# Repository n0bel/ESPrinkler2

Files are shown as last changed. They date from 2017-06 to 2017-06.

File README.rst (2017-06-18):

ESPrinkler2
===========
Arduino/ESP8266 based sprinkler Controller.
-------------------------------------------

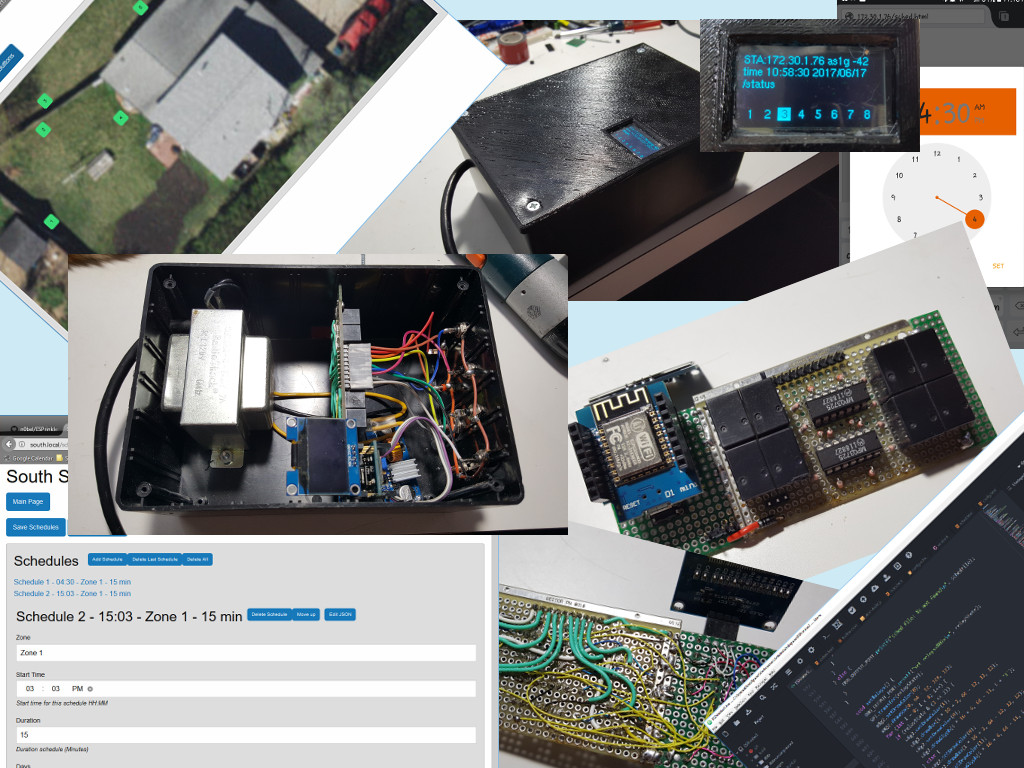
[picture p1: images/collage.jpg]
ESPrinkler2 Collage


This is a totally rewritten second version of
https://github.com/n0bel/ESPrinkler Consider that code now totally
obsolete.

This project uses Arduino/ESP8266 to create a web based lawn/garden
sprinkler controller.

Features
--------
-  Web server based (ESP8266WebServer)
-  Responsive UI (desktop/mobile/tablet) written around Jquery,
   Foundation5, and jsoneditor
-  8 Zones (relays)
-  Up to 30 Schedules
-  NTP Time (or set from browser)
-  RTC Option pcf8563 or ds1307
-  OLED Display Option
-  ArduinoOTA update (code and spiffs)
-  HTTP Server Update (code and spiffs)

Requirements
------------
Hardware
~~~~~~~~
-  ESP-12x (nodemcu, hazza, D1 Mini) (probably others)
-  74HC595
-  ST1306 OLED
-  PCF8563 or ds1307 (optional)
-  Relays

Software
~~~~~~~~
-  Arduino-1.8.3
-  ESP8266/Arduino :Additional Boards Manager URL:
   http://arduino.esp8266.com/stable/package\_esp8266com\_index.json
-  Time 1.5.0 https://github.com/PaulStoffregen/Time
-  SimpleTimer https://github.com/jfturcot/SimpleTimer
   (http://playground.arduino.cc/Code/SimpleTimer)
-  NtpClientLib 2.0.5 https://github.com/gmag11/NtpClient
-  ArduinoJson 5.6.7 https://github.com/bblanchon/ArduinoJson
   (https://bblanchon.github.io/ArduinoJson/)
-  U8G2Lib 2.13.5 https://github.com/olikraus/u8g2
-  orbitalair-arduino-rtc-pcf8563
   https://bitbucket.org/orbitalair/arduino\_rtc\_pcf8563/downloads/
   (https://playground.arduino.cc/Main/RTC-PCF8563)

General Instructions
--------------------

Hardware
~~~~~~~~
This project requires DIY assembly and soldering skills.  At this time there
is no pre-made board.  I've made two of these systems so far, and both of them
are done with proto boards and point to point wiring and assembled in a
water resistant project box.

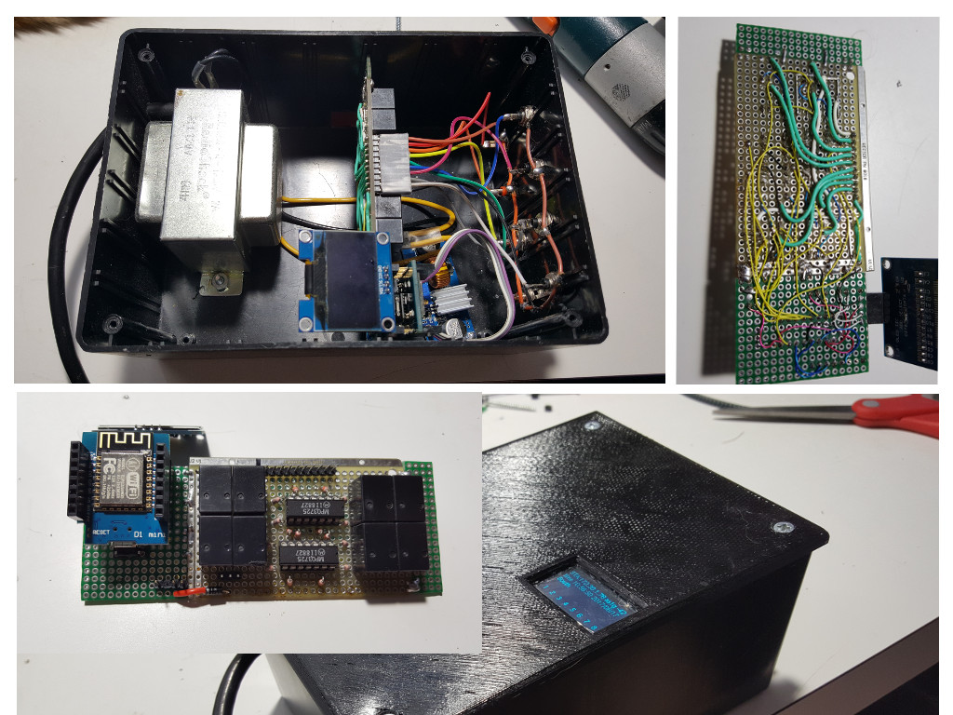
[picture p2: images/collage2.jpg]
ESPrinkler2 An example build


General Hardware Description
^^^^^^^^^^^^^^^^^^^^^^^^^^^^

An ESP8266 with 4MB (32Mb) of flash is required.  The software makes extensive
use of the flash storage for both OTA updates and spiffs.  Generally this is
an ESP-12x, but other models may be used.  In my case I used a WeMos D1 Mini
as the ESP8266 board.  I had some in the junk box and it has the 3.3v
regulator, and the usb to serial interface built on board.  It also includes
a nodemcu type reset and programming circuit.

The 8 relays are controlled through a 74HC595 8 bit shift register.   This is
simply wired to the SPI interface of the ESP8266 (CS (GPIO15), CLK (GPIO14),
MOSI (GPIO13) connected to Latch, Clock and Data In of the 74HC595).

The shift register outputs are then connected via resistors (10k or so) to the
8 NPN transistors acting as relay drivers.  In my particular case I had some
quad transistors in a 14 pin dip package in my junk box.

These transistors then drive 8 mini 5v relays.  The relay contacts connect
24vac to the corresponding output, and therefore energize a sprinkler solenoid.

A 24vac center tapped transformer powers it all.   One leg of the transformer
output is ground for the circuit, the other side is routed to the relays to
control the solenoids.   The center tap is rectified through a single diode
to feed the input of a buck type dc-dc switch mode converter.  The output
of the convert is set to 5v and is routed to the relays and to the D1 Mini.

The ST1306 OLED is an I2C device and therefore connected to SCL (GPIO5)
and SDA (GPIO4) of the ESP8266.

For the optional real time clock (pcf8563 or ds1307), I rigged that up on a
proto board stacked on the D1 Mini using stacking pins.

The following schematic can be used as a guide.  A Fritzing file is also
included.  It is also just a guide.  Again DIY assembly and soldering skills
are required to complete this project.

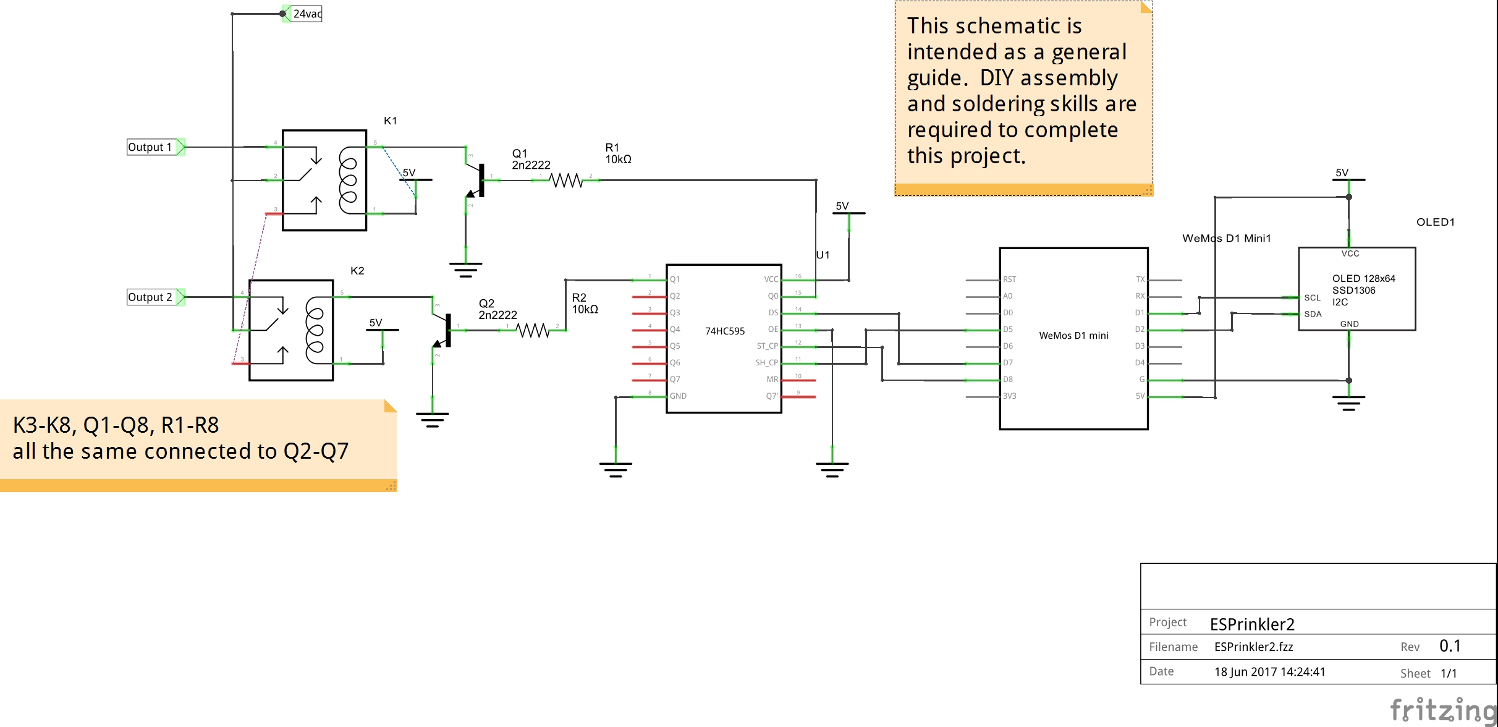
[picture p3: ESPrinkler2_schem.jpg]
ESPrinkler2 Guide Schematic


Software
~~~~~~~~
Don't forget to restart the Arduino IDE after installing the libraries
and boards (See the list previously under Software).

Set your esp settings.. the board, programing method, flash size 4M3M.

This uses the SPIFFS file system. So we need to load that in your
esp-12x first. For quicker loading of web pages, almost all the files on
the spiffs flash are gzip compressed and they have the suffix ".gz".
The uncompressed data version of all the files is the "Master" in the
"data-uncompressed" folder.   The compress-data.cmd file (windows) will
compress the data in preparation for uploading.  If you've not made any
changes to the contents of data-uncompressed, you don't need to do this step.

Upload the contents of the data folder with MkSPIFFS Tool
("ESP8266 Sketch Data Upload" in Tools menu in Arduino IDE)

Then compile and upload the .ino.

Setup
~~~~~
When initially powered on, the internet access point will not be setup.
The ESPrinkler will therefore switch to AP mode. It will be come an
access point in itself.

So connect to ESPrinkler2_XXXXXX with a wifi enabled device (no
password).

Browse to 192.168.4.1

The initial page will let you toggle the relays on/off to test.

But the first thing you'll want to do is click "Set Time from Browser".  Both
the time and the correct time zone are now set up.

Now go to the Configuration page

Set a host name.  This will help allow you to access the device from your
browser (if you can use mDNS).

Set your access point name and password. You have 2 choices here.

-  If you want to connect the device to your network, fill in your access
   point SSID and password.
-  If you want to leave it as a stand alone access point all by itself,
   fill in the second set of SSID and Password, to secure the access point.

Click Save Configuration, then click Restart.

What is it's IP? If your computer supports mDNS (Anything but windows,
but even on windows it'll be there if you have loaded iTunes), you can
access it with the following url: http://<host>.local/, where
<host> is the host you specified in your configuration.  If you don't
have mDNS available, you must find the IP address of the ESPrinkler2
through one of the following methods (or make up your own method)

-  Look at the OLED display (if you're using one)
-  Log into your router and look at the dhcp leases (sometimes called
   dhcp client list) find the entry that shows ESP_xxxxxx
-  Connect a serial ttl dongle to the ESPrinkler2, set the baud rate to
   74880. During startup, you'll see the IP address shown.
-  Get mDNS on your computer: here's some info for windows:
   http://stackoverflow.com/questions/23624525/standard-mdns-service-on-windows
-  ping from a computer that does handle mDNS -- ping <hostname>.local

General usage
~~~~~~~~~~~~~

The Main web page of ESPrinkler2 allows you to test each of the 8 relays. Of
course it also allows navigation to the other pages.  The web pages use a
combination of jQuery, and Foundation5 to create a simple UX that is also
responsive to Desktop, Mobile and Tablet formats.  In addition JsonEditor is
used to simplify entering/editing the settings and schedules.  The frameworks
are all loaded onto the spiffs of the device, so it will work even when no
internet is connected.

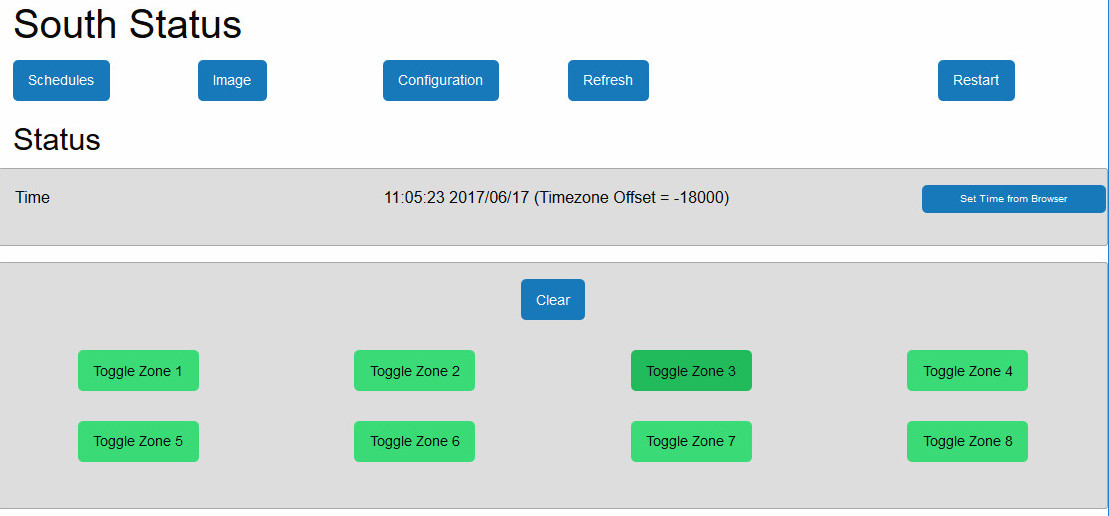
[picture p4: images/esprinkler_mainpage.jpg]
ESPrinkler2 Main Page


The OLED Screen
^^^^^^^^^^^^^^^
The OLED screen gives the current status of the device, as well as its IP
address.

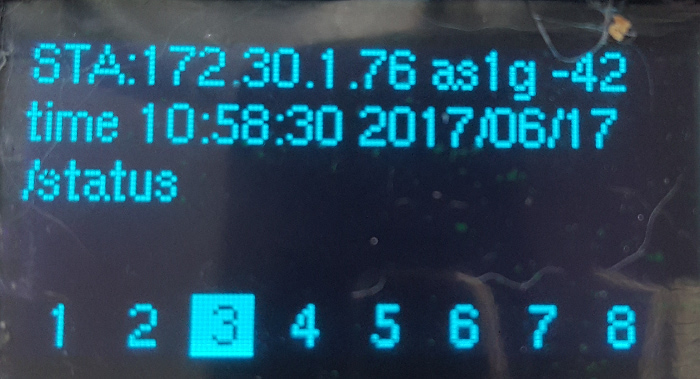
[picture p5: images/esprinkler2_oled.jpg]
ESPrinkler2 OLED Screen


The top line will show the WiFi Status.
-  STA: IP address means connected in Station mode to an access point.
-  AP: IP address means it is acting as an access point.  The second line
   will show the access point name
-  DIS: means it is disconnected.

The bottom line shows that status of each zone (relay).

Schedules
^^^^^^^^^

The schedules page allows adding, specifying and arranging schedules of when
to turn on and off each zone (relay).  Start time, duration, days of week, are
each set for each schedule.  Up to 30 schedules may be setup.

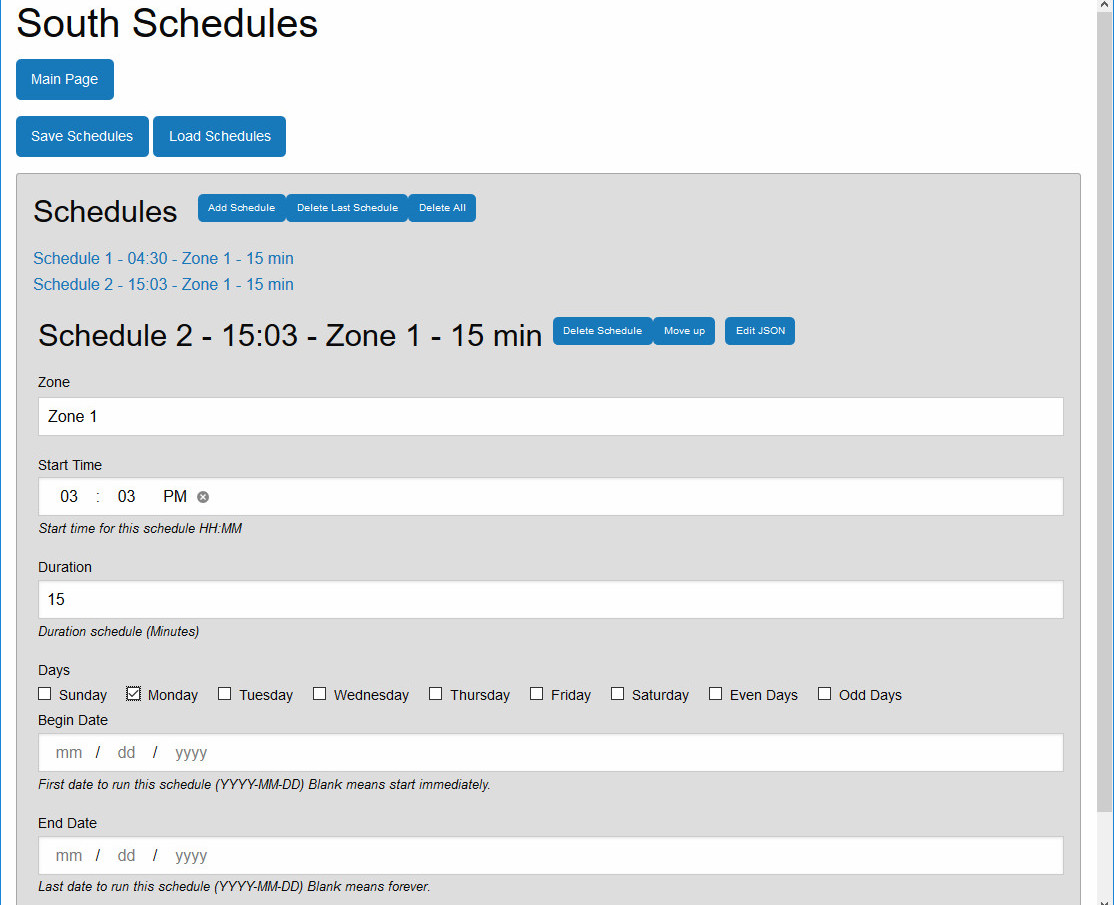
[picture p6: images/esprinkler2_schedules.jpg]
ESPrinkler2 Schedules Page


The Image Page
^^^^^^^^^^^^^^

The image page gives you a graphical representation of each sprinkler zone.
This is handy when testing your sprinklers and setting them up.

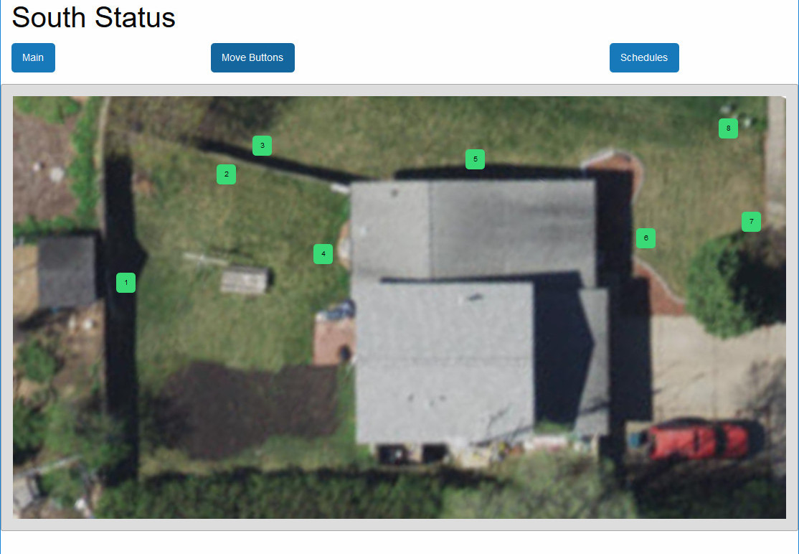
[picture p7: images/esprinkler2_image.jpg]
ESPrinkler2 Image Page


There is a default image supplied, and by default 8 buttons, representing each
zone appear along the top of the image.  The image could be a sketch or a
satellite image of the are the sprinklers are installed.

The "Move Buttons" button can be activated, and the buttons may be moved
around the image (mouse or touch) to indicate which zone is where on the image.
"Save Buttons" then saves the button locations.

The name of the image file is simply "image.jpg" and it can be placed into the
data-uncompressed and/or data folder before loading the spiffs into the device.
It can also be uploaded using the built in spiffs editor (discussed later in
this document.)

Configuration Page
^^^^^^^^^^^^^^^^^^

The configuration page allows you to set the ESPrinkler2 as needed.

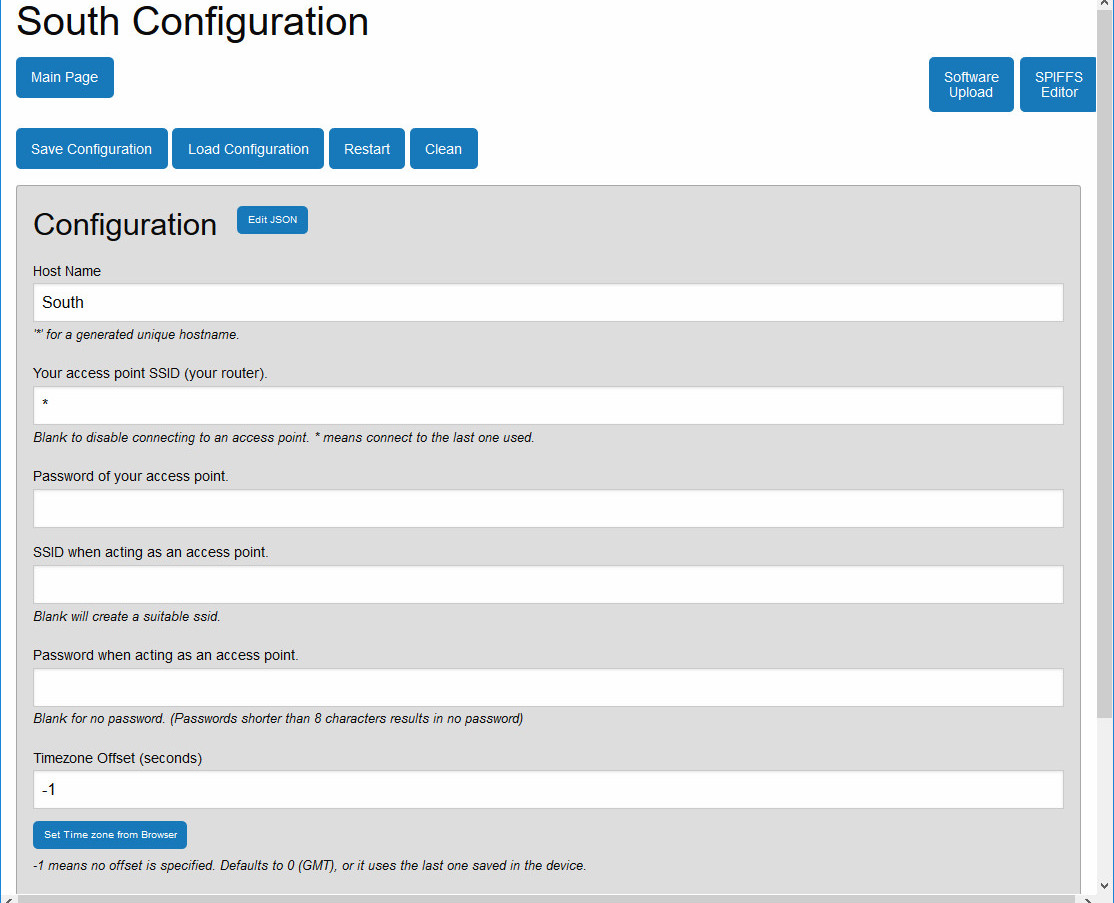
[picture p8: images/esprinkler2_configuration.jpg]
ESPrinkler2 Configuration


The save and load configuration buttons are self explanatory.  Restart is a
reset of the ESP8266.  The "Clean" button clears all configuration (and
schedules and button settings).

+----------------+-------------------------------------------------------+
| Config Item    | Description                                           |
+================+=======================================================+
| Host Name      | The name you give to the device. No spaces allowed    |
|                | The default access point name, and the mDNS name will |
|                | use this name.  If not specified ESPrinkler2_XXXXXX   |
|                | (XXXXXX) is the chipid of the device.                 |
+----------------+-------------------------------------------------------+
| Your Access    | If you want to connect the device to your WiFi network|
| Point SSID     | enter its SSID here.                                  |
+----------------+-------------------------------------------------------+
| Password of    | The password of your access point.                    |
| your Access    |                                                       |
| Point          |                                                       |
+----------------+-------------------------------------------------------+
| SSID when      | If you want the device to act as a stand alone access |
| acting as an   | point (i.e. no internet, only direct connect)         |
| access point   | specify that SSID here.  If blank, it will default as |
|                | the Host Name (or host name default)                  |
+----------------+-------------------------------------------------------+
| Password when  | The password for securing the access point.           |
| acting as an   |                                                       |
| access point   |                                                       |
+----------------+-------------------------------------------------------+
| Timezone       | The timezone offset in seconds.  How many seconds     |
| Offset in      | ahead (positive) or behind (negative) of UTC          |
| seconds        | There is a button to allow this to be set from the    |
|                | browser. If you use -1, the last offset specified by  |
|                | Set Time from browser on the main page will be used.  |
+----------------+-------------------------------------------------------+
| NTP Time Server| What time server to use for getting NTP time.  Note   |
|                | this only works when the device is connected to an    |
|                | access point that has internet access.                |
+----------------+-------------------------------------------------------+

Software Update
^^^^^^^^^^^^^^^

On the Configuration Page, there is a "Software Upload" button.  This allows
new firmware or a new spiffs binary to be loaded directly from your browser.
Simply choose the binary image to upload, and then click "Upload!".
This process can take some time.  You can check progress on the OLED screen.

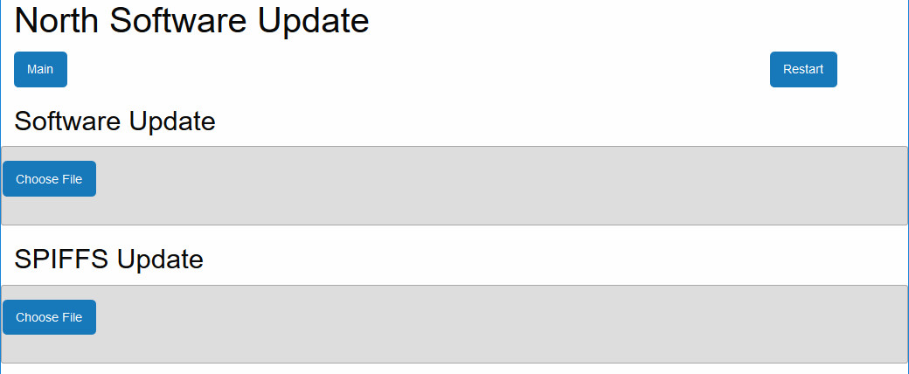
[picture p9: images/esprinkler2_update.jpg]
ESPrinkler2 Update


SPIFFS edit
^^^^^^^^^^^^^^^

On the Configuration Page, there is a "SPIFFS Editor" button.  This allows
you to upload, delete and change the files that the web server uses.

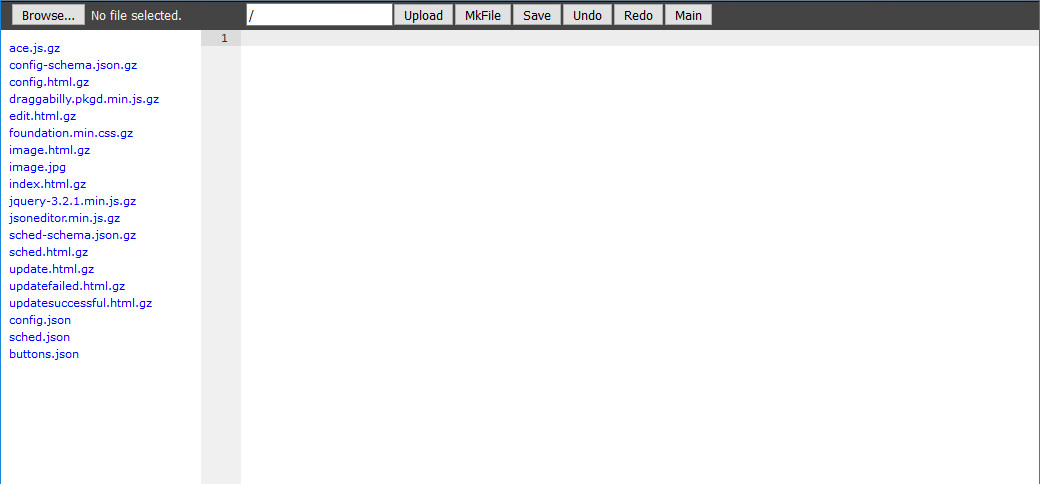
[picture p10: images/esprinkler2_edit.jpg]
ESPrinkler2 SPIFFS editor


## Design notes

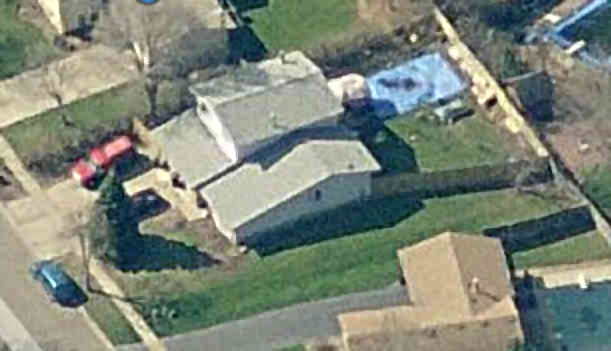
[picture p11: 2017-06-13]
images/house1.jpg

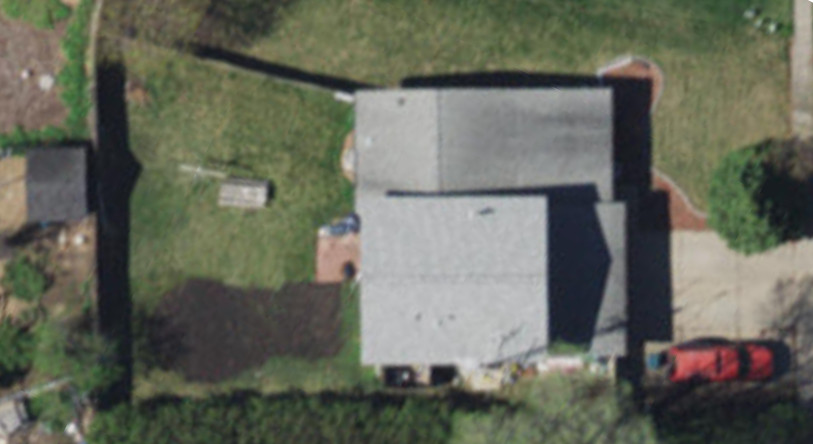
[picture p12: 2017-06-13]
images/house3.jpg

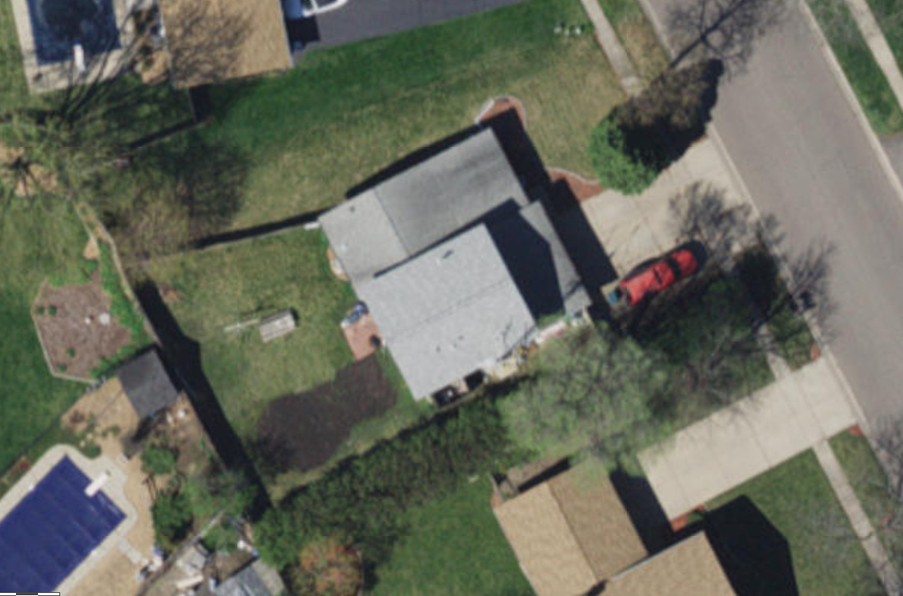
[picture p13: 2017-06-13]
images/house2.jpg

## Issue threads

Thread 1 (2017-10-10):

Cannot create shcedulle more than 8 sched

TeguhTeknisi, 2017-10-10:
I got error when i create more than 8 schedule.
Here some error:
handleFileUpload Name: /sched.json
handleFileUpload Size: 1040
json parse of schedFile failed.

Please help me to solve the problem.

Thanks before.

Meins321, 2020-05-16:
to be honest i don't have this problem, i did build it too witth the wemos d1 mini pro with external antenna and spi flash which is currently not supported...

i can imagine that if you set the flash vs spiff size wrong in arduino ide before you compile and transfer the programm itself the "schedule" file fails due file size..

1.Please test if you run the default setup with nothing changed if you can't create more than 8 tasks

2.Check that you set it to 3M/512k in arduin ide

3. how big is your picture for the Zone Map? <-     :-)

TeguhTeknisi, 2020-05-16:
Hi,
Thanks alot for the reply,I don't play with arduino for around 2 year.but just around 2-3 weeks ago i play with ESPEasy just for setup Temp/Hum Sensor DHT11 and Display 1605 to monitor Temp/Hum in my room and outside my room.
I have delete some of my project files, because i have upgrade my ubuntu, and loose some arduino ide stuff.
And then because i don't know what to do anymore with the ESPrinkler, i move out to OpenSprinkler OSBee - Topic: Need Help to make OSBee Web Offline | OpenSprinkler
|
|
|
|   |    |

   |

  |
|
|   |
Topic: Need Help to make OSBee Web Offline | OpenSprinkler

  |   |

  |

  |

Thats me when i ask some help in the forum, and share my modified osbee sourcecode in there.
i got more fun playing with it, but because some problem (whiteflies,bug,spidermite,etc) with my greenhouse, i have to quit playing with arduino and my greenhouse.
so i'am sory, i cannot answer your question.But for number 3, i use the default picture for zone map, using your.Because my focus still trying to get more schedule, i don't have time to change the picture.
Thanks a lot for your reply and the source code, i have fun and learning from esprinkler2.

Best Regrads,Teguh Teknisi

Sent from Yahoo Mail on Android

  On Sun, May 17, 2020 at 3:57, Meins321<notifications@github.com> wrote:

to be honest i don't have this problem, i did build it too witth the wemos d1 mini pro with external antenna and spi flash which is currently not supported...

i can imagine that if you set the flash vs spiff size wrong in arduino ide before you compile and transfer the programm itself the "schedule" file fails due file size..

1.Please test if you run the default setup with nothing changed if you can't create more than 8 tasks

2.Check that you set it to 3M/512k in arduin ide

   - how big is your picture for the Zone Map? <- :-)

—
You are receiving this because you authored the thread.
Reply to this email directly, view it on GitHub, or unsubscribe.

attiliovaccaro, 2020-10-27:
I had the same problem with even less schedules. The issue is not with the schedules, bud with the length of the generated sched.json which shall be less than 1000 characters.
I tried to increase it to 1500 by changing a couple of lines of code in the loadSched() function and it works. I also tried with larger values, but the system does not work (it continuously reboots after connecting to the WIFI).
I guess that a way to solve this would be to modify the names of attributes/nodes used in sched.json using shorter ones, this would imply some further changes in the code and schema.

Meins321, 2022-02-16:
@attiliovaccaro Can you share more insight? i have created more than 8 shedules back then when i answered and it worked maybe i did test it wrong?

lethedream007, 2022-05-22:
@attiliovaccaro
Not quite sure what core version you are using. I'm using 2.7.4 (NodeMCU ESP8266) and I cannot change the size of the json array without introducing issues (mainly to the WIFI). However, I did find that, if I enable the debug port and set the debug level to "WIFI" or "CORE", everything works. I can even increase the json array size to [5000] with DynamicJsonBuffer, which should allow plenty of schedules.

@Meins321 I think it is also about what boxes you check when you set the schedule. It's very possible that 8 schedules don't run over 1000 characters.

I'm still puzzled why I must enable debug port for "WIFI" or "CORE" to make the code work. I have been reading random post online and it could be related to some variables not initialized correctly, race condition, etc. I'm lost...

YengaJaf-Aizatron, 2024-06-26:
This is an old issue, but what I did was to increase the stack size of the main loop, and increase the jsondoc size. At first I made the JsonDoc size 5000, but then I ran into a stack overflow issue. What fixed it was this line which I placed right at the beginning of the main.c file:
`/*
Increase stack of main loop, Default 8k
This was done to allow schedules more than 8 to work
*/
SET_LOOP_TASK_STACK_SIZE(16*1024);`

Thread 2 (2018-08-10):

Support for this premade board?

oleost, 2018-08-10:
Hi.

Any chance this could work on this premade board?

"Esp8266 4ch 12v wifi relay"
https://www.aliexpress.com/item/ESP8266-4CH-12V-WiFi-Relay-Module-Smart-Home-Mobile-APP-Remote-Control-Switch/32879651251.html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,searchweb201602_1_10152_10065_10151_10344_10068_10342_10343_10340_10059_10341_5012011_10696_100031_5011911_10084_10083_10103_10618_10307_10624_10623_10622_10621_10620,searchweb201603_54,ppcSwitch_2&algo_expid=5b4c92ad-dcd2-4901-8fda-b2b61f445251-0&algo_pvid=5b4c92ad-dcd2-4901-8fda-b2b61f445251&transAbTest=ae803_2&priceBeautifyAB=0

Without oled support ofc, and only limited to 4 outputs.

theevilshiftkey, 2019-01-14:
I don't think that the ESP01 has enough memory for this project. If I have time (not likely) I may fork this to work on some premade board not yet researched, since I only need one zone/output.

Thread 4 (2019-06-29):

Designed PCB for this project

glenosAU, 2019-06-29:
I have designed a PCB to use for this project, based off the images from your build. Happy to take any feedback on my board design.
https://easyeda.com/glen_3116/esprinkler

I'm going to start cobbling this project together this weekend  to try and get it working and then order the boards once its running.

pbezza, 2019-07-09:
I see your PCB has pads for a master relay on D6. Does the code support a master relay? Also, are Darlington transistors necessary to drive the relay board inputs? I'm about to order parts and want to make sure I have everything before I solder.

glenosAU, 2019-07-09:
The fork being maintained by lawabb includes a master relay and he recommends the Darlington array.

I drew the PCB when I had some spare time while waiting for parts to arrive. I haven't got the circuit working yet. There was an error in my design where the shift register was powered by VCC (3.3v) I have changed it to be 5V.

pbezza, 2019-07-09:
I didn't know it was forked - I had to google for lawabb on github to find his fork. I am setting up my sprinkler manifold at the moment which has a master solenoid so I will utilise the fork. Thanks.

Regarding the Darlington array - the relay boards are opto isolated so I'll leave the Darlington ic out and drive my 8 channel relay board directly.

My relay board has 3.3v inputs and from what I can see, the shift register works at 3.3v.

Meins321, 2020-04-11:
Level Sensor sounds like a kill switch for the pump if there is no Water :-)

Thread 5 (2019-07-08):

Manual Zone Activation Via Panel

pbezza, 2019-07-08:
Fantastic project. I will start making this in a couple of days. Any chance of adding support for manual activation of zones via the panel? I would love to have buttons on the panel that have configurable on times in minutes (via the web interface) for manual activation of zones. Are you able to add this feature?

Meins321, 2020-04-11:
Yes manual buttons are missing to test sprinklers and nanually turn on and offf

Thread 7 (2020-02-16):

Request

marsman007, 2020-02-16:
- Would it be possible to see the status of the relays (buttons turns red if active)?
- Would it be possible to have a parameter for entering the port number of the server in STA mode?

Meins321, 2020-05-16:
If you run this code on your board it will show it:
https://github.com/lawabb/ESPrinkler2
RED active
Green Inactive

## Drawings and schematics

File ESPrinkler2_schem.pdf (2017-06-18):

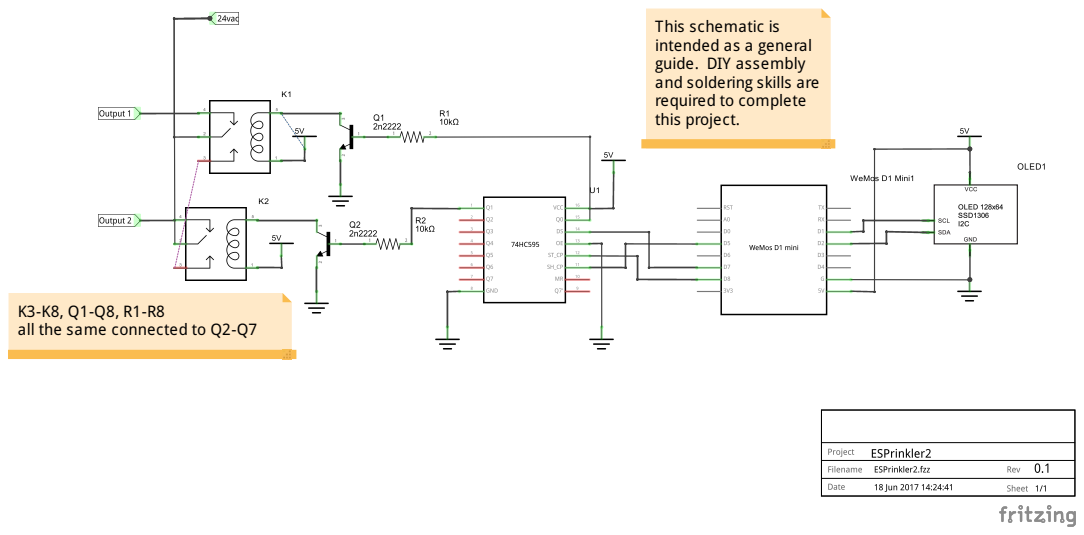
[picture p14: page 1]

This schematic is
intended as a general
guide. DIY assembly
and soldering skills are
required to complete
this project.

all the same connected to Q2-Q7

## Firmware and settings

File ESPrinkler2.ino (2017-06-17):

/*
 ESPrinkler2 -- Web Server Enabled Sprinkler Controller
 https://github.com/n0bel/ESPrinkler2
 Original Base code is https://github.com/esp8266/Arduino/blob/master/libraries/ESP8266WebServer/examples/FSBrowser/FSBrowser.ino
 Base Code Copyright (c) 2015 Hristo Gochkov. All rights reserved. LGPL
 This Code Copyright (c) 2017 Kevin Uhlir. All rights reserved. LGPL
 This is a rewrite of ESPrinkler https://github.com/n0bel/ESPrinkler but based
 on the Arduino toolchain instead of ExperssIF.  This should make the project
 more accessable to people.
*/

/* Requirements:
  Arduino-1.8.3
  ESP8266/Arduino :Additional Boards Manager URL: http://arduino.esp8266.com/stable/package_esp8266com_index.json
  Time 1.5.0 https://github.com/PaulStoffregen/Time
  SimpleTimer https://github.com/jfturcot/SimpleTimer (http://playground.arduino.cc/Code/SimpleTimer)
  NtpClientLib 2.0.5 https://github.com/gmag11/NtpClient
  ArduinoJson 5.6.7 https://github.com/bblanchon/ArduinoJson (https://bblanchon.github.io/ArduinoJson/)
  U8G2Lib 2.13.5 https://github.com/olikraus/u8g2
  orbitalair-arduino-rtc-pcf8563  https://bitbucket.org/orbitalair/arduino_rtc_pcf8563/downloads/ (https://playground.arduino.cc/Main/RTC-PCF8563)

  Don't forget to restart the Arduino IDE after installing these things.


  Set your esp settings.. the board, program method, flash size and spiffs size.

  This uses the SPIFFS file system.  So we need to load that in your esp-xx first.
  Upload the contents of the data folder with MkSPIFFS Tool ("ESP8266 Sketch Data Upload" in Tools menu in Arduino IDE)

  Then compile and upload the .ino.

  */

// Configurable Options

// Include code for PCF8563 RTC
#define INCLUDE_PCF8563

// Include code for DS1307 RTC
#define INCLUDE_DS1307

// Where Do you want to send debug output?
#define DBG_OUTPUT_PORT Serial

// Uncommment if you'd like even more debug information
// #define EXTRA_DEBUG

// End of Config

#include <ESP8266WiFi.h>
#include <WiFiClient.h>
#include <ESP8266WebServer.h>
#include <ESP8266mDNS.h>
#include <ArduinoOTA.h>
#include <DNSServer.h>
#include <TimeLib.h>
#include <NtpClientLib.h>
#include <FS.h>
#include <stdarg.h>

#include <ArduinoJson.h>
#include <string.h>
#include <U8g2lib.h>
#include <SimpleTimer.h>
#include <SPI.h>
#include <Wire.h>
#include <EEPROM.h>
#define EEPROM_SIZE 512

#ifdef INCLUDE_PCF8563
#include <Rtc_Pcf8563.h>
#endif
#ifdef INCLUDE_DS1307
#include <RtcDS1307.h>
#endif

#include "./version.h"

U8G2_SH1106_128X64_NONAME_F_HW_I2C u8g2(U8G2_R2, U8X8_PIN_NONE);

#ifdef INCLUDE_PCF8563
Rtc_Pcf8563 Rtc_Pcf8563;
#endif
#ifdef INCLUDE_DS1307
RtcDS1307<TwoWire> Rtc_Ds1307(Wire);
#endif

const char* configFile = "/config.json";   // The config file name
const char* schedFile = "/sched.json";   // The sched file name
const char* buttonsFile = "/buttons.json";   // The buttons file name

// Note that these are the default values if no /config.json exists,
//  or items are missing from it.

char ssid[31] = { "" };              // This is the access point to connect to
#define EEPROM_SSID 0                 // where the ssid is kept in EEPROM
char password[31] = { "" };           // And its password
#define EEPROM_PASSWORD 32            // where the password is kept in EEPROM
char host[31] = { "*" };               // The host name .local (mdns) hostname
#define EEPROM_HOST 64                // where the host is kept in EEPROM
char assid[31] = { "" };              // This is the access point to connect to
char apassword[31] = { "" };          // And its password

int offsetGMT = 0;                    // Local timezone offset in seconds
char offsetGMTstring[10] = { "-1" };  // String version of it
#define EEPROM_OFFSET_GMT 96          // where the host is kept in EEPROM
int relayState = 0;                   // The current state of the relayState

bool apMode = false;                  // Are we in Acess Point mode?
bool dnsStarted = false;              // Did we start dns?
#ifdef INCLUDE_PCF8563
bool hasPcf8563 = false;              // we found a PCF8563
#endif
#ifdef INCLUDE_DS1307
bool hasDs1307 = false;              // we found a PCF8563
#endif
bool hasRtc = false;                  // do we have an rtc
bool rtcValid  = false;               // does it have a valid time
time_t bootTime = 0;
String bootTimeString;

char timeServer[31] = { "pool.ntp.org" };   // the NTP timeServer to use

#define MAX_SCHED 30
struct _sched {
  int zone;       // 1-8 and 100 for reset
  int days;       // day bits 0-6 = sunday-saturday and 8 and 9 are even and odd
  time_t start;   // seconds like 02:00 am is 120 * 3600
  int duration;   // minutes
  time_t begin;   // begin date
  time_t end;     // end date
  time_t next;    // next time this should turn on a relay
  time_t stop;    // when the relay should turn off
} sched[MAX_SCHED] = { 0 };


// DNS server
const byte DNS_PORT = 53;
DNSServer dnsServer;

ESP8266WebServer server(80);  // The Web Server
File fsUploadFile;            // holds the current upload when files are
                              // uploaded (see edit.htm)
SimpleTimer timer;

int priorPct = -1;
int fullSize = -1;

// format bytes
String formatBytes(size_t bytes) {
  if (bytes < 1024) {
    return String(bytes)+"B";
  } else if (bytes < (1024 * 1024)) {
    return String(bytes/1024.0)+"KB";
  } else if (bytes < (1024 * 1024 * 1024)) {
    return String(bytes/1024.0/1024.0)+"MB";
  } else {
    return String(bytes/1024.0/1024.0/1024.0)+"GB";
  }
}

String getContentType(String filename) {
  if (server.hasArg("download")) return "application/octet-stream";
  else if (filename.endsWith(".htm")) return "text/html";
  else if (filename.endsWith(".html")) return "text/html";
  else if (filename.endsWith(".css")) return "text/css";
  else if (filename.endsWith(".js")) return "application/javascript";
  else if (filename.endsWith(".json")) return "text/json";
  else if (filename.endsWith(".png")) return "image/png";
  else if (filename.endsWith(".gif")) return "image/gif";
  else if (filename.endsWith(".jpg")) return "image/jpeg";
  else if (filename.endsWith(".ico")) return "image/x-icon";
  else if (filename.endsWith(".xml")) return "text/xml";
  else if (filename.endsWith(".pdf")) return "application/x-pdf";
  else if (filename.endsWith(".zip")) return "application/x-zip";
  else if (filename.endsWith(".gz")) return "application/x-gzip";
  return "text/plain";
}

bool handleFileRead(String path) {
  DBG_OUTPUT_PORT.printf(" handleFileRead: %s\n",
    path.c_str());
  displayStatus(2, "served %s", path.c_str());
  if (path.endsWith("/")) path += "index.html";
  String ims = server.header("If-Modified-Since");
  String contentType = getContentType(path);
  String pathWithGz = path + ".gz";
  if (SPIFFS.exists(pathWithGz) || SPIFFS.exists(path)) {
    if (bootTimeString != "" && bootTimeString == ims) {
      server.send(304, contentType, "Not Modified");
      return true;
    }
    if (SPIFFS.exists(pathWithGz))
      path += ".gz";
    File file = SPIFFS.open(path, "r");
    if (path.indexOf(".json") < 0 || path.indexOf("-schema.json") > -1) {
        server.sendHeader("Cache-Control", "public, max-age=3600");
        if (bootTime > 0) {
          server.sendHeader("Last-Modified", bootTimeString);
        }
    } else {
      server.sendHeader("Cache-Control", "public, max-age=0");
    }
    size_t sent = server.streamFile(file, contentType);
    file.close();
    return true;
  }
  DBG_OUTPUT_PORT.printf("%s not found\n", path.c_str());
  return false;
}

void handleFileUpdate() {
  HTTPUpload& update = server.upload();
  if (update.status == UPLOAD_FILE_START) {
    String filename = update.filename;
    fullSize = atoi(server.header("Content-Length").c_str());
    priorPct = 0;
    DBG_OUTPUT_PORT.printf("handleFileUpdate Name: %s %d\n",
      filename.c_str(), fullSize);
    displayStatus(1, "HTTP Update start");
    if (server.uri() == "/spiffsupdate") {
      if (!Update.begin(fullSize, U_SPIFFS)) {
        Update.printError(DBG_OUTPUT_PORT);
      }
    } else {
      uint32_t maxSketchSpace = (ESP.getFreeSketchSpace() - 0x1000)
        & 0xFFFFF000;
      if (!Update.begin(maxSketchSpace)) {
        Update.printError(DBG_OUTPUT_PORT);
      }
    }
  } else if (update.status == UPLOAD_FILE_WRITE) {
    int p = update.totalSize / (fullSize / 100);
    if ((p - priorPct) >= 5) {
      priorPct = p;
      DBG_OUTPUT_PORT.printf("Update: %u%%\n", p);
      displayStatus(1, "HTTP Update %u%", p);
    }
    if (Update.write(update.buf, update.currentSize) != update.currentSize) {
      Update.printError(DBG_OUTPUT_PORT);
      displayStatus(1, "HTTP Update Failed");
    }
  } else if (update.status == UPLOAD_FILE_END) {
    if (Update.end(true)) {
      DBG_OUTPUT_PORT.printf("Update Success: %u\nRebooting...\n",
        update.totalSize);
      displayStatus(1, "HTTP Update End");
    } else {
      Update.printError(DBG_OUTPUT_PORT);
    }
  } else if (update.status == UPLOAD_FILE_ABORTED) {
    Update.end();
    DBG_OUTPUT_PORT.printf("Update aborted.\n");
    displayStatus(1, "HTTP Update aborted");
  }
}
void afterFileUpdate() {
  server.sendHeader("Location",
    String(Update.hasError() ? "/updatefailed.html" :
      "/updatesuccessful.html"), true);
  server.send(301, "text/html", "");
  doRestart();
}

void handleFileUpload() {
  if (server.uri() != "/edit") return;
  HTTPUpload& upload = server.upload();
  if (upload.status == UPLOAD_FILE_START) {
    String filename = upload.filename;
    if (!filename.startsWith("/")) filename = "/"+filename;
    displayStatus(2, "upload %s", filename.c_str());
    DBG_OUTPUT_PORT.printf("handleFileUpload Name: %s\n", filename.c_str());
    fsUploadFile = SPIFFS.open(filename, "w");
    filename = String();
  } else if (upload.status == UPLOAD_FILE_WRITE) {
    // DBG_OUTPUT_PORT.printf("handleFileUpload Data: %s\n",upload.currentSize);
    if (fsUploadFile)
      fsUploadFile.write(upload.buf, upload.currentSize);
  } else if (upload.status == UPLOAD_FILE_END) {
    if (fsUploadFile)
      fsUploadFile.close();
    DBG_OUTPUT_PORT.printf("handleFileUpload Size: %d\n", upload.totalSize);
    if (upload.filename == configFile) {
      loadConfig();
    }
    if (upload.filename == schedFile) {
      loadSched();
    }
  }
}

void handleFileDelete() {
  if (server.args() == 0) return server.send(500, "text/plain", "BAD ARGS");
  String path = server.arg(0);
  DBG_OUTPUT_PORT.printf("handleFileDelete: %s\n", path.c_str());
  displayStatus(2, "deleted %s", path.c_str());
  if (path == "/")
    return server.send(500, "text/plain", "BAD PATH");
  if (!SPIFFS.exists(path))
    return server.send(404, "text/plain", "FileNotFound");
  SPIFFS.remove(path);
  server.send(200, "text/plain", "");
  path = String();
}

void handleFileCreate() {
  if (server.args() == 0)
    return server.send(500, "text/plain", "BAD ARGS");
  String path = server.arg(0);
  DBG_OUTPUT_PORT.printf("handleFileCreate: %s\n", path.c_str());
  displayStatus(2, "created %s", path.c_str());
  if (path == "/")
    return server.send(500, "text/plain", "BAD PATH");
  if (SPIFFS.exists(path))
    return server.send(500, "text/plain", "FILE EXISTS");
  File file = SPIFFS.open(path, "w");
  if (file)
    file.close();
  else
    return server.send(500, "text/plain", "CREATE FAILED");
  server.send(200, "text/plain", "");
  path = String();
}

void handleFileList() {
  if (!server.hasArg("dir")) {
    server.send(500, "text/plain", "BAD ARGS"); return;
  }

  String path = server.arg("dir");
  DBG_OUTPUT_PORT.printf(" handleFileList: %s\n", path.c_str());
  displayStatus(2, "list %s", path.c_str());
  Dir dir = SPIFFS.openDir(path);
  path = String();

  String output = "[";
  while (dir.next()) {
    File entry = dir.openFile("r");
    if (output != "[") output += ',';
    bool isDir = false;
    output += "{\"type\":\"";
    output += (isDir)?"dir":"file";
    output += "\",\"name\":\"";
    output += String(entry.name()).substring(1);
    output += "\"}";
    entry.close();
  }

  output += "]";
  server.sendHeader("Cache-Control", "public, max-age=0");
  server.send(200, "text/json", output);
}

void eeSave();  // forward ref
void loadConfig() {
  if (SPIFFS.exists(configFile)) {
    File file = SPIFFS.open(configFile, "r");
    char json[500];
    memset(json, 0, sizeof(json));
    file.readBytes(json, sizeof(json));
    file.close();
    StaticJsonBuffer<500> jsonBuffer;
    JsonObject& root = jsonBuffer.parseObject(json);
    if (!root.success()) {
        DBG_OUTPUT_PORT.printf("json parse of configFile failed.\n");
    } else {
      const char *t;
      t = root["ssid"]; if (t && t[0] != '*') {
        strncpy(ssid, t, 30);
        t = root["password"]; if (t) { strncpy(password, t, 30); }
      }
      t = root["assid"]; if (t) { strncpy(assid, t, 30); }
      t = root["apassword"]; if (t) { strncpy(apassword, t, 30); }
      t = root["host"]; if (t) { strncpy(host, t, 30); }
      t = root["timeServer"]; if (t) { strncpy(timeServer, t, 30); }
      t = root["offsetGMT"]; if (t) { strncpy(offsetGMTstring, t, 10); }
      int g = atoi(offsetGMTstring);
      if (g != -1) {
        offsetGMT = g;
      }
      setHostName();
      displayStatus(2, host);
      eeSave();
      DBG_OUTPUT_PORT.printf("Config: host: %s ssid: %s assid: %s\n",
        host, ssid, assid);
      DBG_OUTPUT_PORT.printf("  timeServer: %s offsetGMT:%d\n",
        timeServer, offsetGMT);
    }
  } else {
    DBG_OUTPUT_PORT.printf("config file: %s not found\n", configFile);
  }
}

int computeDayFromTm(tmElements_t *tm) {
  // bits 0-6 = day of week
  // bits 8 == even Day
  // bit 9 == odd Day
  return (1 << (tm->Wday - 1)) | ( 1 << ((tm->Day & 1) + 8));
}

#ifdef EXTRA_DEBUG
void dumpSched(const char *m, struct _sched *s) {
  DBG_OUTPUT_PORT.printf(
    "%s: %08x z:%d s:%d d:%02x b:%d e:%d n:%d o:%d d:%d\n",
    m, s, s->zone, s->start, s->days, s->begin, s->end,
    s->next, s->stop, s->duration);
    DBG_OUTPUT_PORT.printf("%s: next:%s",
      m, timeStr(s->next+offsetGMT));
    DBG_OUTPUT_PORT.printf(" stop:%s\n", timeStr(s->stop+offsetGMT));
}
#endif

void xxdoRestart() {
  ESP.restart();
}

void doRestart() {
  displayStatus(0, "Restarting.....");
  DBG_OUTPUT_PORT.printf("Restart in 5 seconds.\n");
  timer.setTimeout(5000, []() { ESP.restart(); });
}
void computeNext(struct _sched *s) {
  if (now() < 10000000) {
    s->next = s->stop = 0;
    return;
  }
  time_t midnightLocal = (now() + offsetGMT) / 86400;
  if (s->begin > 10000000 && s->begin > now())
    midnightLocal = s->begin / 86400;
  midnightLocal = midnightLocal * 86400;
  time_t midnightLocalAsGmt = midnightLocal - offsetGMT;
  int day = 0xffff;
  s->next = midnightLocalAsGmt + s->start - 86400;
  do {
    s->next += 86400;
    tmElements_t tm;
    breakTime(s->next + offsetGMT, tm);
    day = computeDayFromTm(&tm);
    if (s->next > s->end) {
      s->next = 0;
      break;
    }
    #ifdef EXTRA_DEBUG
    dumpSched("computeNext", s);
    DBG_OUTPUT_PORT.printf("computeNext: day=%02x tm.Day=%d tm.Wday=%d\n",
      day, tm.Day, tm.Wday);
    #endif
  } while (now() >= s->next
      || (day & (s->days)) == 0);
  if (s->stop == 0 && s->next > 0) {
    s->stop = s->next + s->duration;
  }
}

void checkSched() {
  time_t timeNow = now();
  for (int i = 0; i < MAX_SCHED; i++) {
    if (sched[i].zone > 0) {
      #ifdef EXTRA_DEBUG
      dumpSched("checkSched", &sched[i]);
      #endif
      if (sched[i].stop > 0 && timeNow >= sched[i].stop) {
        sched[i].stop = 0;
        if (sched[i].next > 0) {
          sched[i].stop = sched[i].next + sched[i].duration;
        }
        if (sched[i].zone < 9) {
          relayState &= ~(1 << (sched[i].zone - 1));
          setRelays();
        }
      }
      if (sched[i].next > 0 && timeNow >= sched[i].next) {
        if (sched[i].zone == 100) {
          doRestart();
        } else {
          relayState |= (1 << (sched[i].zone - 1));
          setRelays();
        }
        computeNext(&sched[i]);
      }
    }
  }
}

void recalcSched() {
  for (int i = 0; i < MAX_SCHED; i++) {
    if (sched[i].zone > 0) {
      computeNext(&sched[i]);
    }
  }
}

void loadSched() {
  if (SPIFFS.exists(schedFile)) {
    File file = SPIFFS.open(schedFile, "r");
    char json[1000];
    memset(json, 0, sizeof(json));
    file.readBytes(json, sizeof(json));
    file.close();
    StaticJsonBuffer<1000> jsonBuffer;
    JsonArray& root = jsonBuffer.parseArray(json);
    if (!root.success()) {
        DBG_OUTPUT_PORT.printf("json parse of schedFile failed.\n");
    } else {
      tmElements_t tm;
      relayState = 0;
      setRelays();
      for (int i = 0; i < MAX_SCHED; i++) {
        const char *zoneString = root[i]["zone"];
        const char *startTime = root[i]["startTime"];
        sched[i].zone = 0;
        sched[i].next = 0;
        sched[i].duration = 0;
        sched[i].stop = 0;
        if (zoneString && zoneString[0] != '\0'
            && startTime && startTime[0] != '\0') {
//
          if (strstr(zoneString, "Zone ") == zoneString) {
            sched[i].zone = zoneString[5] - '0';
          }

          if (strstr(zoneString, "Restart") == zoneString) {
            sched[i].zone = 100;
          }

          sched[i].start = atoi(startTime) * 3600 +
                           atoi(startTime + 3) * 60;

          const char *beginDate = root[i]["begin"];
          if (!beginDate || beginDate[0] == '\0') {
            sched[i].begin = 10000000;   // more or less beginning of time
          } else  {
            tm.Second = tm.Hour = tm.Minute = tm.Wday = 0;
            tm.Year = atoi(beginDate) - 1970;
            tm.Month = atoi(beginDate+5);
            tm.Day = atoi(beginDate+8);
            sched[i].begin = makeTime(tm) - offsetGMT;
          }

          const char *endDate = root[i]["end"];
          if (!endDate || endDate[0] == '\0') {
            sched[i].end = 0x7fffffff;   // more or less end of time
          } else {
            tm.Second = tm.Hour = tm.Minute = tm.Wday = 0;
            tm.Year = atoi(endDate) - 1970;
            tm.Month = atoi(endDate+5);
            tm.Day = atoi(endDate+8);
            sched[i].end = makeTime(tm) - offsetGMT;
          }

          const char *duration = root[i]["duration"];
          if (!duration || duration[0] == '\0') {
            sched[i].duration = 15 * 60;  // default = 15 minutes
          } else {
            sched[i].duration = atoi(duration) * 60;
          }


          sched[i].days = 0;
          for (int j = 0; j < 10; j++) {
            const char *dayString = root[i]["days"][j];
            if (!dayString) break;
            if (strstr(dayString, "Sunday") == dayString )
              sched[i].days |= 1 << 0;
            if (strstr(dayString, "Monday") == dayString )
              sched[i].days |= 1 << 1;
            if (strstr(dayString, "Tuesday") == dayString )
              sched[i].days |= 1 << 2;
            if (strstr(dayString, "Wednesday") == dayString )
              sched[i].days |= 1 << 3;
            if (strstr(dayString, "Thursday") == dayString )
              sched[i].days |= 1 << 4;
            if (strstr(dayString, "Friday") == dayString )
              sched[i].days |= 1 << 5;
            if (strstr(dayString, "Saturday") == dayString )
              sched[i].days |= 1 << 6;
            if (strstr(dayString, "Even") == dayString )
              sched[i].days |= 1 << 8;
            if (strstr(dayString, "Odd") == dayString )
            sched[i].days |= 1 << 9;
          }
          if (sched[i].days == 0) sched[i].days = 0xffff;

          computeNext(&sched[i]);

          #ifdef EXTRA_DEBUG
          dumpSched("schedlist", &sched[i]);
          #endif
          DBG_OUTPUT_PORT.printf("schedule %d loaded next: %s duration %d\n",
              i, timeStr(sched[i].next + offsetGMT), sched[i].duration);
        }
      }
    }
  } else {
    DBG_OUTPUT_PORT.printf("sched file: %s not found\n", schedFile);
  }
}

void setRelays() {
  DBG_OUTPUT_PORT.printf("set relays=%02x\n", relayState);
  SPI.transfer(relayState);
  u8g2.setDrawColor(0);
  u8g2.drawBox(0, 64 - 12, 128, 12);
  for (int i = 0; i < 8; i++) {
    if (relayState & (1 << i)) {
      u8g2.setDrawColor(1);
      u8g2.drawBox(i * 16 + 2, 64 - 12, 12, 12);
      u8g2.setDrawColor(0);
      u8g2.drawGlyph(i * 16 + 6, 64 - 11, i + '1');
    } else {
      u8g2.setDrawColor(0);
      u8g2.drawBox(i * 16 + 2, 64 - 12, 12, 12);
      u8g2.setDrawColor(1);
      u8g2.drawGlyph(i * 16 + 6, 64 - 11, i + '1');
    }
  }
  u8g2.sendBuffer();
}

void displayStatus(int line, const char *fmt, ...) {
  int count;
  char *buffer;
  va_list Arglist;

  count = 0;
  buffer = reinterpret_cast<char*>(malloc(128));
  if (buffer == NULL) return;
  va_start(Arglist, fmt);
  vsnprintf(buffer, 128, fmt, Arglist); // NOLINT

  u8g2.setDrawColor(0);
  u8g2.drawBox(0, line * 12, 128, 12);
  u8g2.setDrawColor(1);
  u8g2.drawStr(0, line * 12, buffer);
  u8g2.sendBuffer();
  free(buffer);
}
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
void loop(void) {
// deal with timer (SimpleTimer)
  timer.run();
// deal with http server.
  server.handleClient();
  ArduinoOTA.handle();
  if (dnsStarted) dnsServer.processNextRequest();
  if (DBG_OUTPUT_PORT.available()) {
    String line = DBG_OUTPUT_PORT.readStringUntil('\r');
    DBG_OUTPUT_PORT.printf("%s\n", line.c_str());

    char buf[100];
    line.toCharArray(buf, sizeof(buf));
    char *p = buf;
    char *str;
    char *args[10];
    int argc = 0;
    while ((str = strtok_r(p, " ", &p)) != NULL && argc < 10) {
      args[argc++] = str;
    }
    if (argc >= 3 && strcmp(args[0], "ap") == 0) {
      strncpy(ssid, args[1], sizeof(ssid));
      strncpy(password, args[2], sizeof(password));
      eeSave();
      doRestart();
    }
  }
}

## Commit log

2017-06-03 More progress and linter fixes
    [ESPrinkler2.ino]
2017-06-03 More linting and printf cleanup
2017-06-05 All the wrong stuff in the gallery
    [ESPrinkler2.ino]
2017-06-08 change to arduino-1.8.3 and add com port list to build
2017-06-12 Persist ssid, password and timezone offset in the device (eeprom)
2017-06-14 Moving buttons on mobile device
2017-06-16 Config, Default, and Schema Issues
    [ESPrinkler2.ino]
2017-06-18 Schematic and Docs
    [ESPrinkler2.fzz]
